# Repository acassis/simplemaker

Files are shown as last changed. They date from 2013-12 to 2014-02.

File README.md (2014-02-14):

simplemaker
===========

This is my FirstCNC design!

It is based on http://www.thingiverse.com/thing:41594

This project started as an evolution from TheMarker2 CNC replacing the PIC microcontroller by an Atmega, but eventually I decided to move to this thingiverse design because it is more robust.

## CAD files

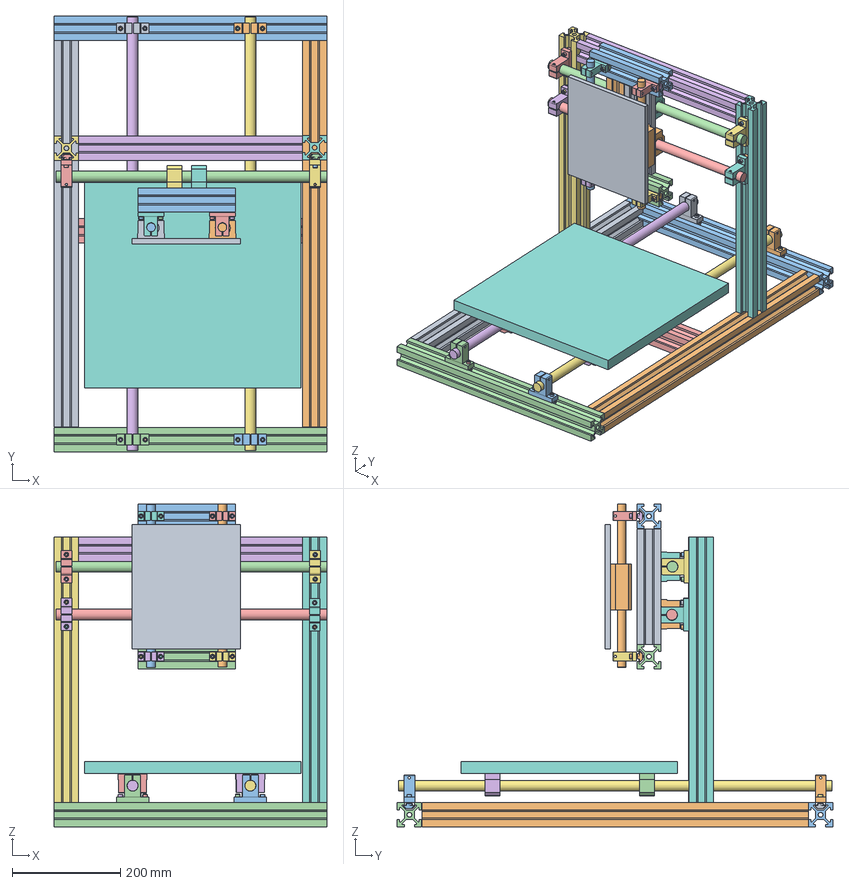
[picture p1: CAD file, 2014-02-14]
design/first_cnc.fcstd
503.0 x 803.7 x 595.9 mm
Left
Right
Back
Front
Inner_base
Inner_gantry
gantry_left
gantry_right
Plate_Z
Shaft_Z_Right
Shaft_Z_Left
Shaft_Y_Top
Shaft_Y_Bottom
Shaft_X_Left
Shaft_X_Right
Bed
M6_Tnut_slot
M6_Tnut_slot001
M6_Tnut_slot002
M6_Tnut_slot003
M6_Tnut_slot004
M6_Tnut_slot005
M6_Tnut_slot006
M6_Tnut_slot007
M6_Tnut_slot008
M6_Tnut_slot009
M6_Tnut_slot010
M6_Tnut_slot011
M6_Tnut_slot012
M6_Tnut_slot013
M6_Tnut_slot014
M6_Tnut_slot015
Right_Z
Left_Z
SC20VUU
SC20VUU001
SC20VUU002
SC20VUU003
SC20VUU004
SC20VUU005
SC20VUU006
SC20VUU007
Top_Z
Bottom_Z
M6_Tnut_slot10
M6_Tnut_slot016
M6_Tnut_slot017
M6_Tnut_slot018
M6_Tnut_slot020
M6_Tnut_slot021
M6_Tnut_slot022
M6_Tnut_slot023
M6_Tnut_slot024
M6_Tnut_slot025
M6_Tnut_slot026
M6_Tnut_slot027
M6_Tnut_slot028
M6_Tnut_slot029
M6_Tnut_slot030
M6_Tnut_slot031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

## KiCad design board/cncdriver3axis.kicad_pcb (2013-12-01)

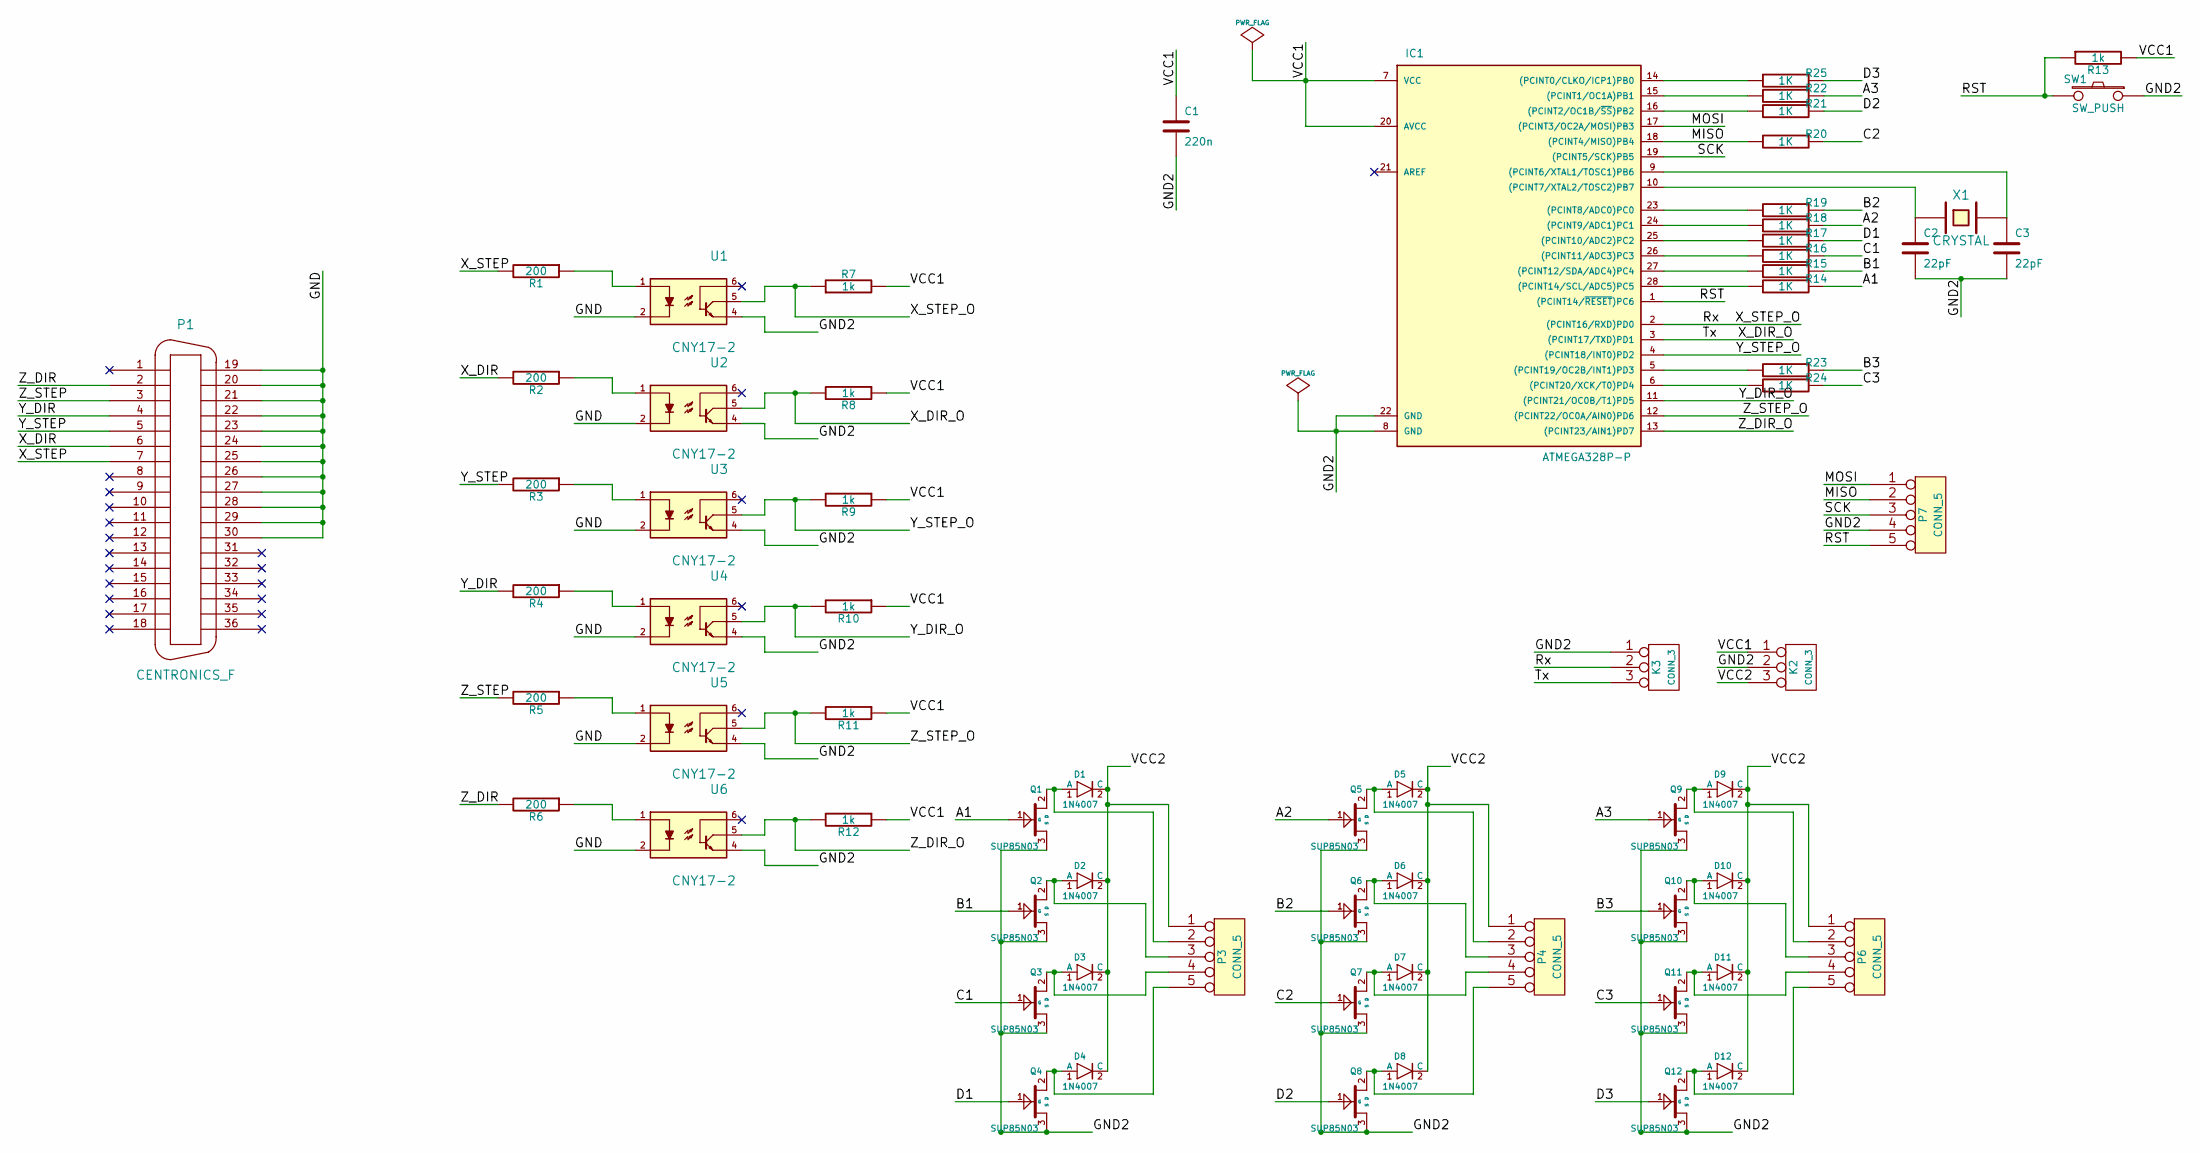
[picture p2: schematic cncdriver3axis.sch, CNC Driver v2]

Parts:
C1: 220n
C2, C3: 22pF
D1, D2, D3, D4, D5, D6, D7, D8, D9, D10, D11, D12: 1N4007; DO7
IC1: ATMEGA328P-P; DIL28
K2, K3: CONN_3
P1: CENTRONICS_F
P3, P4, P6, P7: CONN_5
Q1, Q2, Q3, Q4, Q5, Q6, Q7, Q8, Q9, Q10, Q11, Q12: SUP85N03
R1, R2, R3, R4, R5, R6: 200
R7, R8, R9, R10, R11, R12, R13: 1k
R14, R15, R16, R17, R18, R19, R20, R21, R22, R23, R24, R25: 1K
SW1: SW_PUSH
U1, U2, U3, U4, U5, U6: CNY17-2
X1: CRYSTAL

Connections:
/A1: Q1.1 (G), R14.1
/A2: Q5.1 (G), R18.1
/A3: Q9.1 (G), R22.1
/B1: Q2.1 (G), R15.1
/B2: Q6.1 (G), R19.1
/B3: Q10.1 (G), R23.1
/C1: Q3.1 (G), R16.1
/C2: Q7.1 (G), R20.1
/C3: Q11.1 (G), R24.1
/D1: Q4.1 (G), R17.1
/D2: Q8.1 (G), R21.1
/D3: Q12.1 (G), R25.1
/GND: P1.19, P1.20, P1.21, P1.22, P1.23, P1.24, P1.25, P1.26, P1.27, P1.28, P1.29, P1.30, U1.2, U2.2, U3.2, U4.2, U5.2, U6.2
/GND2: C1.2, C2.2, C3.2, IC1.8 (GND), IC1.22 (GND), K2.2 (PM), K3.1, P7.4, Q1.3 (S), Q2.3 (S), Q3.3 (S), Q4.3 (S), Q5.3 (S), Q6.3 (S), Q7.3 (S), Q8.3 (S), Q9.3 (S), Q10.3 (S), Q11.3 (S), Q12.3 (S), SW1.1, U1.4, U2.4, U3.4, U4.4, U5.4, U6.4
/MISO: IC1.18 ((PCINT4/MISO)PB4), P7.2, R20.2
/MOSI: IC1.17 ((PCINT3/OC2A/MOSI)PB3), P7.1
/RST: IC1.1 ((PCINT14/~RESET~)PC6), P7.5, R13.1, SW1.2
/Rx: IC1.2 ((PCINT16/RXD)PD0), K3.2 (PM), R7.1, U1.5
/SCK: IC1.19 ((PCINT5/SCK)PB5), P7.3
/Tx: IC1.3 ((PCINT17/TXD)PD1), K3.3, R8.2, U2.5
/VCC1: C1.1, IC1.7 (VCC), IC1.20 (AVCC), K2.1, R7.2, R8.1, R9.1, R10.1, R11.1, R12.1, R13.2
/VCC2: D1.2 (C), D2.2 (C), D3.2 (C), D4.2 (C), D5.2 (C), D6.2 (C), D7.2 (C), D8.2 (C), D9.2 (C), D10.2 (C), D11.2 (C), D12.2 (C), K2.3, P3.1, P4.1, P6.1
/X_DIR: P1.6, R2.2
/X_STEP: P1.7, R1.2
/Y_DIR: P1.4, R4.2
/Y_DIR_O: IC1.11 ((PCINT21/OC0B/T1)PD5), R10.2, U4.5
/Y_STEP: P1.5, R3.2
/Y_STEP_O: IC1.4 ((PCINT18/INT0)PD2), R9.2, U3.5
/Z_DIR: P1.2, R6.2
/Z_DIR_O: IC1.13 ((PCINT23/AIN1)PD7), R12.2, U6.5
/Z_STEP: P1.3, R5.2
/Z_STEP_O: IC1.12 ((PCINT22/OC0A/AIN0)PD6), R11.2, U5.5
unnamed: R2.1, U2.1
unnamed: R4.1, U4.1
unnamed: R6.1, U6.1
unnamed: D4.1 (A), P3.5, Q4.2 (D)
unnamed: R1.1, U1.1
unnamed: R5.1, U5.1
unnamed: D10.1 (A), P6.3, Q10.2 (D)
unnamed: D5.1 (A), P4.2, Q5.2 (D)
unnamed: IC1.5 ((PCINT19/OC2B/INT1)PD3), R23.2
unnamed: IC1.6 ((PCINT20/XCK/T0)PD4), R24.2
unnamed: R3.1, U3.1
unnamed: D6.1 (A), P4.3, Q6.2 (D)
unnamed: D8.1 (A), P4.5, Q8.2 (D)
unnamed: D7.1 (A), P4.4, Q7.2 (D)
unnamed: D2.1 (A), P3.3, Q2.2 (D)
unnamed: IC1.14 ((PCINT0/CLKO/ICP1)PB0), R25.2
unnamed: IC1.24 ((PCINT9/ADC1)PC1), R18.2
unnamed: IC1.27 ((PCINT12/SDA/ADC4)PC4), R15.2
unnamed: IC1.25 ((PCINT10/ADC2)PC2), R17.2
unnamed: C3.1, IC1.9 ((PCINT6/XTAL1/TOSC1)PB6), X1.2
unnamed: D9.1 (A), P6.2, Q9.2 (D)
unnamed: D11.1 (A), P6.4, Q11.2 (D)
unnamed: D12.1 (A), P6.5, Q12.2 (D)
unnamed: C2.1, IC1.10 ((PCINT7/XTAL2/TOSC2)PB7), X1.1
unnamed: IC1.28 ((PCINT14/SCL/ADC5)PC5), R14.2
unnamed: IC1.16 ((PCINT2/OC1B/~SS~)PB2), R21.2
unnamed: IC1.15 ((PCINT1/OC1A)PB1), R22.2
unnamed: IC1.23 ((PCINT8/ADC0)PC0), R19.2
unnamed: IC1.26 ((PCINT11/ADC3)PC3), R16.2
unnamed: D1.1 (A), P3.2, Q1.2 (D)
unnamed: D3.1 (A), P3.4, Q3.2 (D)

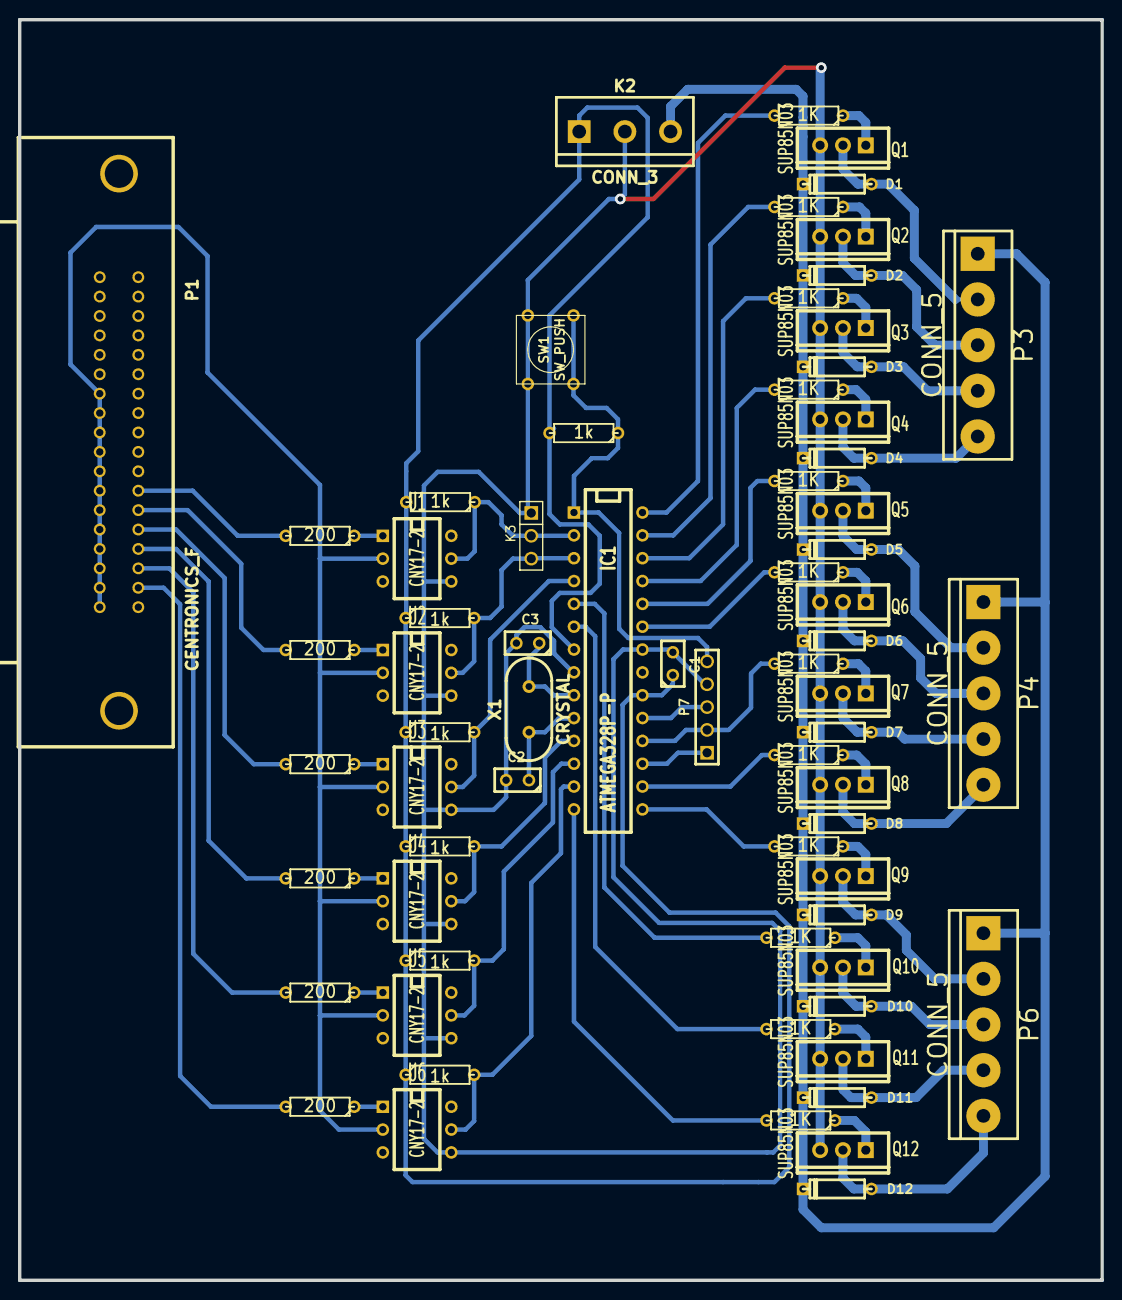
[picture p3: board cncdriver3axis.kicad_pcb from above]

Board: 2 copper layers, 120.4 x 140.2 mm, 68 parts (0 on the bottom side), 63 nets.

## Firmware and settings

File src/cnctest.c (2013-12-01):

#include <avr/io.h>
#include <util/delay.h>

#ifndef F_CPU
#define F_CPU 16000000UL           /* Clock Frequency = 16Mhz */
#endif

#define SPEED 9600

#define X_STEP (1 << 0)
#define X_DIR  (1 << 1)

#define Y_STEP (1 << 2)
#define Y_DIR  (1 << 5)

#define Z_STEP (1 << 6)
#define Z_DIR  (1 << 7)

int modeX = 0;
int stepX = 0;

int modeY = 0;
int stepY = 0;

int modeZ = 0;
int stepZ = 0;

#define A1(N)	do { PORTC &= ~(_BV(PC5)); PORTC |= (N << PC5); } while(0)
#define B1(N)	do { PORTC &= ~(_BV(PC4)); PORTC |= (N << PC4); } while(0)
#define C1(N)	do { PORTC &= ~(_BV(PC3)); PORTC |= (N << PC3); } while(0)
#define D1(N)	do { PORTC &= ~(_BV(PC2)); PORTC |= (N << PC2); } while(0)

#define A2(N)	do { PORTC &= ~(_BV(PC1)); PORTC |= (N << PC1); } while(0)
#define B2(N)	do { PORTC &= ~(_BV(PC0)); PORTC |= (N << PC0); } while(0)
#define C2(N)	do { PORTB &= ~(_BV(PB4)); PORTB |= (N << PB4); } while(0)
#define D2(N)	do { PORTB &= ~(_BV(PB2)); PORTB |= (N << PB2); } while(0)

#define A3(N)	do { PORTB &= ~(_BV(PB1)); PORTB |= (N << PB1); } while(0)
#define B3(N)	do { PORTD &= ~(_BV(PD3)); PORTD |= (N << PD3); } while(0)
#define C3(N)	do { PORTD &= ~(_BV(PD4)); PORTD |= (N << PD4); } while(0)
#define D3(N)	do { PORTB &= ~(_BV(PB0)); PORTB |= (N << PB0); } while(0)


void changeStepX(int dir){
	if(dir)
		stepX = (++stepX) % 4;
	else
		stepX = (--stepX) % 4;
	
	if(stepX==0){
		A1(1);
		B1(1);
		C1(0);
		D1(0);
	}else if(stepX==1){
		A1(0);
		B1(1);
		C1(1);
		D1(0);
	}else if(stepX==2){
		A1(0);
		B1(0);
		C1(1);
		D1(1);
	}else if(stepX==3){
		A1(1);
		B1(0);
		C1(0);
		D1(1);
	}
}

void changeStepY(int dir){
	if(dir)
		stepY = (++stepY) % 4;
	else
		stepY = (--stepY) % 4;
	
	if(stepY==0){
		A2(1);
		B2(1);
		C2(0);
		D2(0);
	}else if(stepY==1){
		A2(0);
		B2(1);
		C2(1);
		D2(0);
	}else if(stepY==2){
		A2(0);
		B2(0);
		C2(1);
		D2(1);
	}else if(stepY==3){
		A2(1);
		B2(0);
		C2(0);
		D2(1);
	}
}

void changeStepZ(int dir){
	if(dir)
		stepZ = (++stepZ) % 4;
	else
		stepZ = (--stepZ) % 4;
	
	if(stepZ==0){
		A3(1);
		B3(1);
		C3(0);
		D3(0);
	}else if(stepZ==1){
		A3(0);
		B3(1);
		C3(1);
		D3(0);
	}else if(stepZ==2){
		A3(0);
		B3(0);
		C3(1);
		D3(1);
	}else if(stepZ==3){
		A3(1);
		B3(0);
		C3(0);
		D3(1);
	}
}

static void serial_init(unsigned int bittimer)
{
	/* Set the baud rate */
	UBRR0H = (unsigned char) (bittimer >> 8);
	UBRR0L = (unsigned char) bittimer;
	/* set the framing to 8N1 */
	UCSR0C = (3 << UCSZ00);
	/* Engage! */
	UCSR0B = (1 << RXEN0) | (1 << TXEN0);
	return;
}

static void serial_write(unsigned char c)
{
	while ( !(UCSR0A & (1 << UDRE0)) )
		;
	UDR0 = c;
}

int main (void)
{

	int i = 0;
	char *str
          = "XS = X XD = X YS = Y YD = Y ZS = Z ZD = Z\r\n";

	/* set PORTB for output*/
	DDRB = 0xFF;

	/* set PORTC for output*/
	DDRC = 0xFF;

	/* set PORTD[0,1,2,5,6,7] for input and PORTD[3,4] output*/
	DDRD = 0x18;

        /* set pull-up for all input pins */
	PORTD = ~(0x18);

	/* let the preprocessor calculate this */
	serial_init( ( F_CPU / SPEED / 16 ) - 1);

	if(PIND & X_STEP){
		modeX = 1;
	}else{
		modeX = 0;
	}
	
	if(PIND & Y_STEP){
		modeY = 1;
	}else{
		modeY = 0;
	}	
	
	if(PIND & Z_STEP){
		modeZ = 1;
	}else{
		modeZ = 0;
	}	

	modeZ = 0;
	
	while(1){
		if(modeX == 0){
			if(PIND & X_STEP){
				modeX = 1;
				if(PIND & X_DIR){
					changeStepX(1);
				}else{
					changeStepX(0);
				}
			}
					
		}else{
			if(!(PIND & X_STEP)){
				modeX = 0;
			}
		}
	
		if(modeY == 0){
			if(PIND & Y_STEP){
				modeY = 1;
				if(PIND & Y_DIR){
					changeStepY(1);
				}else{
					changeStepY(0);
				}
			}
					
		}else{
			if(!(PIND & Y_STEP)){
				modeY = 0;
			}
		}		
		
		if(modeZ == 0){
			if(PIND & Z_STEP){
				modeZ = 1;
				if(PIND & Z_DIR){
					changeStepZ(1);
				}else{
					changeStepZ(0);
				}
			}
					
		}else{
			if(!(PIND & Z_STEP)){
				modeZ = 0;
			}
		}		
		
	}

	/* while (1) {

		if (PIND & X_STEP)
			str[5]='1';
		else
			str[5]='0';

		if (PIND & X_DIR)
			str[12]='1';
		else
			str[12]='0';


		if (PIND & Y_STEP)
			str[19]='1';
		else
			str[19]='0';

		if (PIND & Y_DIR)
			str[26]='1';
		else
			str[26]='0';


		if (PIND & Z_STEP)
			str[33]='1';
		else
			str[33]='0';

		if (PIND & Z_DIR)
			str[40]='1';
		else
			str[40]='0';


		//USART_putstring(str);
		serial_write(str[i++]);
		if (str[i] == '\0') {
			i = 0;
			_delay_ms(500);
		}

	}*/
	return 0;
}

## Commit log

2013-12-01 Initial commit to add schematic and source code of SimpleMaker
    [cncdriver3axis.dsn, cncdriver3axis.kicad_pcb, cncdriver3axis.sch]
2014-02-14 Add FreeCAD design
    [first_cnc.fcstd]
